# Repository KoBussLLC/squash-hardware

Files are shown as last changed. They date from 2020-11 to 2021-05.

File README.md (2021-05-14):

# Squash Keyboard Hardware

Small keyboard for big brains with lots of layers
🤏 ⌨️ 🧠 🍰

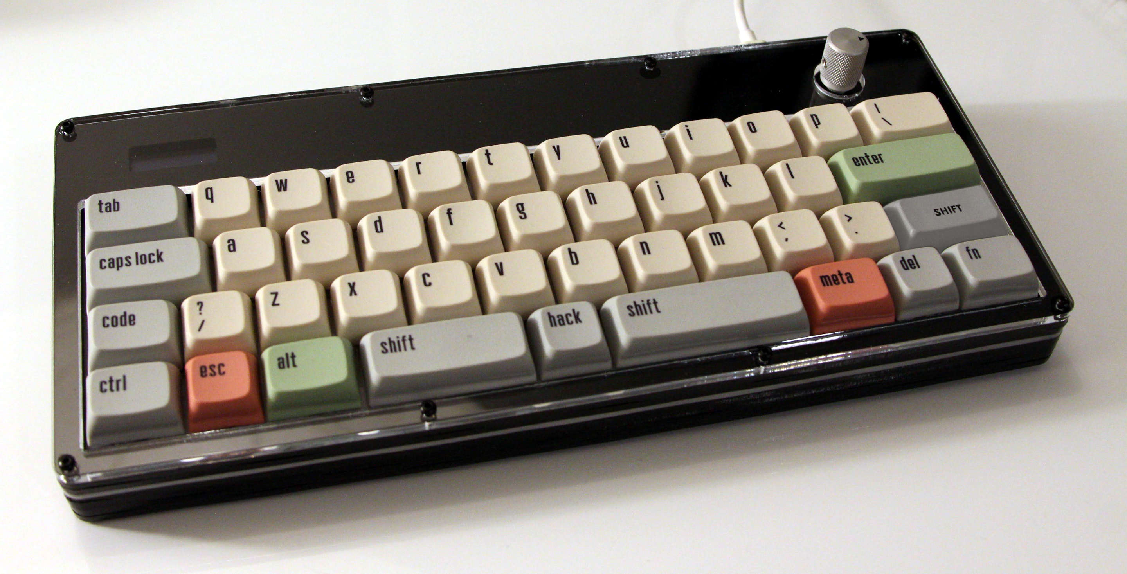
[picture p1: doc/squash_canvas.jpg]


This keyboard uses an acrylic case, POM switch-plate, and PCB mounted switches and stabilizers.

See Squash's bigger brother for [build instructions](https://github.com/KoBussLLC/grabert-hardware/blob/main/doc/BUILDGUIDE.md) and [additional information](https://github.com/KoBussLLC/grabert-hardware/blob/main/README.md).

## Layout

[Keyboard Layout Editor Permalink](http://www.keyboard-layout-editor.com/##@@_x:2.75&w:1.5%3B&=0,0&=0,1&=0,2&=0,3&=0,4&=0,5&=0,6&=0,7&=0,8&=0,9&=0,10&_w:1.5%3B&=0,11%3B&@_x:2.75&w:1.75%3B&=1,0&=1,1&=1,2&=1,3&=1,4&=1,5&=1,6&=1,7&=1,8&=1,9&_w:2.25%3B&=1,10%3B&@_x:0.25&w:1.25%3B&=2,0%0A%0A%0A0,1&=2,1%0A%0A%0A0,1&_x:0.25&w:2.25%3B&=2,0%0A%0A%0A0,0&=2,2&=2,3&=2,4&=2,5&=2,6&=2,7&=2,8&=2,9&=2,10&_w:1.75%3B&=2,11%3B&@_x:2.75&c=%23AAAAAA&w:1.25%3B&=3,0&=3,1&=3,2%0A%0A%0A1,0&_c=%23cccccc&w:6.25%3B&=3,4%0A%0A%0A1,0&_c=%23AAAAAA&w:1.25%3B&=3,6&=3,7&_w:1.25%3B&=3,8%3B&@_y:0.25&x:5&w:1.25%3B&=3,2%0A%0A%0A1,1&_c=%23cccccc&w:2.25%3B&=3,3%0A%0A%0A1,1&=3,4%0A%0A%0A1,1&_w:2.75%3B&=3,5%0A%0A%0A1,1&_x:4%3B&=3,11) for layout options.

A standard keycap set can be used as long as each "row" has the same profile and a 1.75u right shift key is included.

## PCB

This project uses KiCad for electrical CAD

### Electrical Design Constraings
- No diode matrix enabled by LQFP 100 Footprint
- STM32 Based Micro-controller
- USB-C
- PWM LED indicators for Caps Lock and modifiers
- PCB Mount switches
- Enocder and I2C OLED Display

## CAD

This project uses FreeCAD 0.19 for mechanical CAD. File names are prefixed with a unique, arbitrary alphanumeric code with the first character always being a alpha character.

### Required Addons
- Assembly 4
- fasteners
- kicadStepUpMod

### Mechanical Design Constraints
- 40% Keyboard Layout
- Split spacebar and left shift layout options
- Push Button Encoder
- OLED Screen
- Fully Laser Cut Case

### Acrylic Sheet Stackup

Main Case Stackup. 0 is the bottom of the case. Foot pieces are included in the D65_USBCutoutSpacer.svg file and are assembled with the smallest piece on the bottom.

| Sheet Number | FreeCAD File Name | Thickness | Material | Shape |
| - | - | - | - | - |
| 0 | O56_BottomPlate | 0.125 in | Acrylic |  |
| 1 | Y7X_ClosedSpacer | 0.125 in | Acrylic |  |
| 2 | D65_USBCutoutSpacer | 0.125 in | Acrylic |  *includes foot pieces |
| 3 | D65_USBCutoutSpacer | 0.125 in | Acrylic |  *includes foot pieces |
| 4 | S86_SwitchPlate | 0.0625 in | POM/Acetal |  |
| 5 | Y7X_ClosedSpacer | 0.125 in | Acrylic |  |
| 6 | Q45_OLEDCover | 0.125 in | Acrylic |  |
| 7 | O03_TopCover | 0.125 in | Acrylic |  |

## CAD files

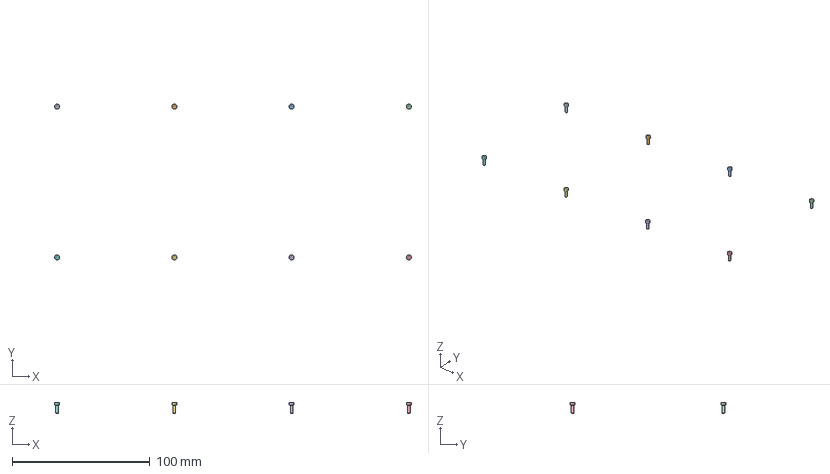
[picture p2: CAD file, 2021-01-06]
CAD/L32_Squash.FCStd
259.4 x 113.3 x 8.00 mm
M2x6-Screw001
M2x6-Screw
M2x6-Screw002
M2x6-Screw003
M2x6-Screw005
M2x6-Screw006
M2x6-Screw007
M2x6-Screw008

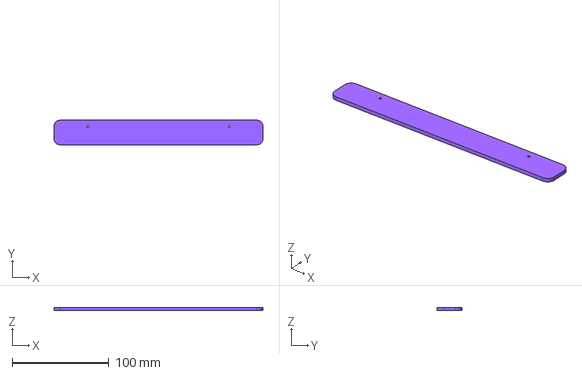
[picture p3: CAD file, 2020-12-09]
CAD/X23_Foot2.FCStd
215.9 x 25.4 x 3.17 mm

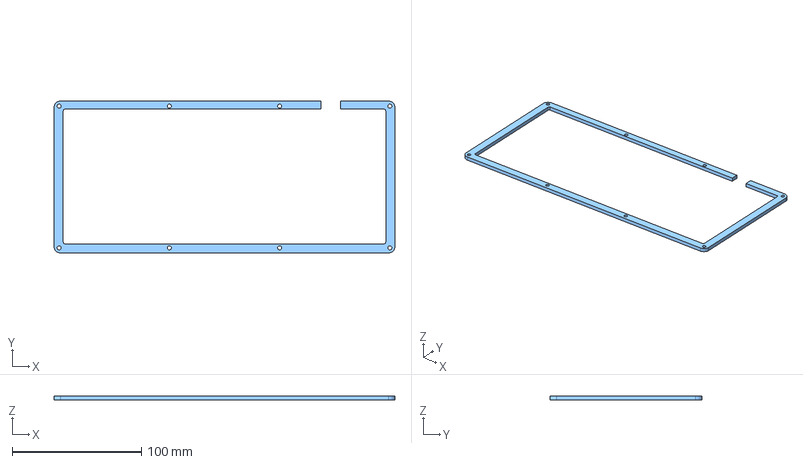
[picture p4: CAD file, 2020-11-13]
CAD/D65_USBCutoutSpacer.FCStd
263.5 x 117.5 x 3.17 mm

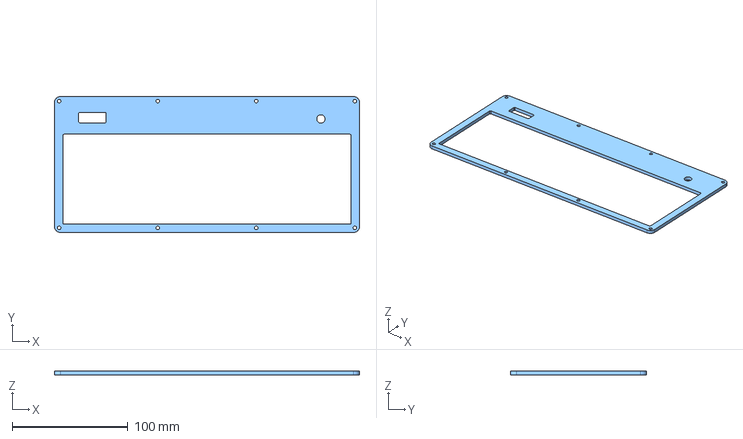
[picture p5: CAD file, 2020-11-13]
CAD/Q45_OLEDCover.FCStd
263.5 x 117.5 x 3.17 mm

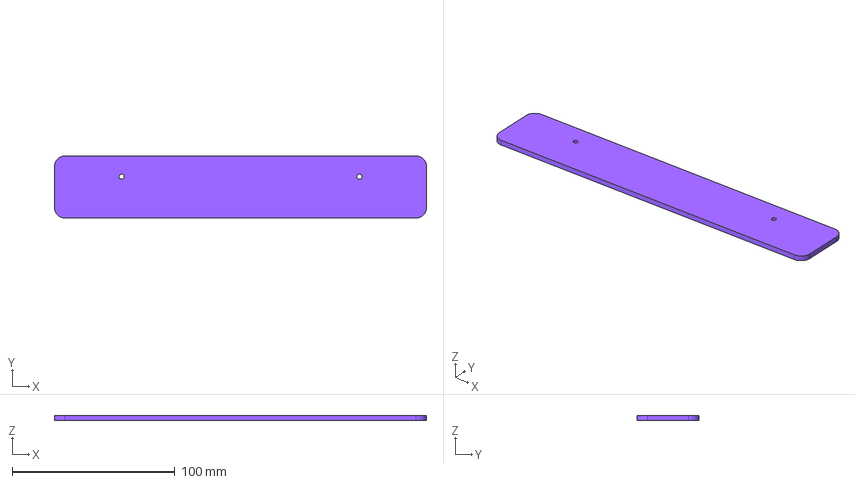
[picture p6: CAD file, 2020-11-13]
CAD/X21_Foot0.FCStd
228.6 x 38.1 x 3.17 mm

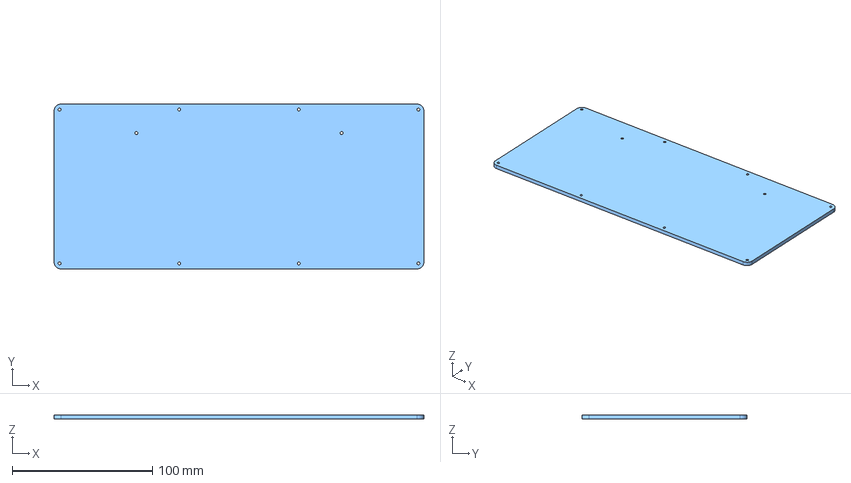
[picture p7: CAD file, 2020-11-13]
CAD/O56_BottomPlate.FCStd
263.5 x 117.5 x 3.17 mm

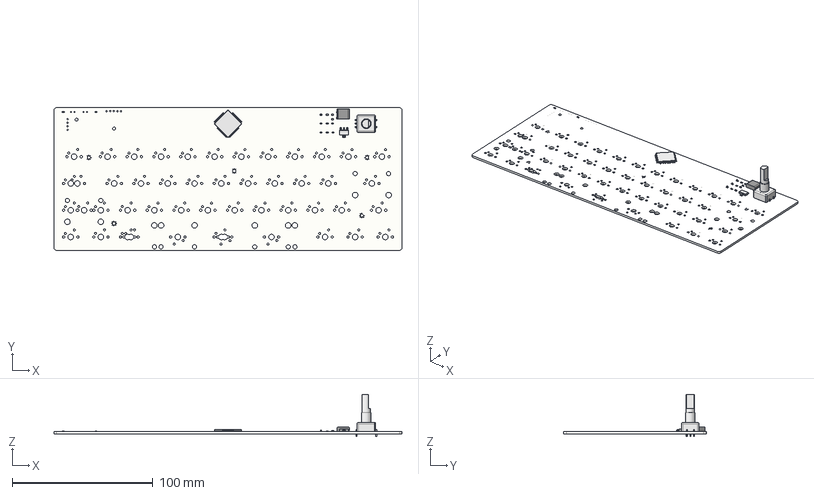
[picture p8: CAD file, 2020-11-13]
CAD/R79_SquashPCB.FCStd
247.7 x 101.6 x 30.2 mm
Pcb_de64
ROT_ENC1_PEC11R-4220K-S0024_5F30CEA1
U2_SOT_223_5F285D89
USBC1_U262-161N-4BVC11_5F1FC831
C1_C_0603_1608Metric_5F1FC55F x 2
D1_LED_0603_1608Metric_5F30C0E4 x 3
R1_R_0603_1608Metric_5F30E40D x 7
U1_LQFP_100_14x14mm_P05mm_5F30CB79

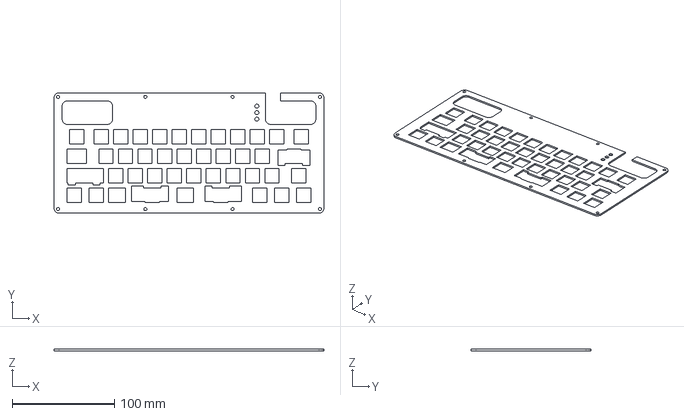
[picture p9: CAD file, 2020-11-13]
CAD/S86_SwitchPlate.FCStd
263.5 x 117.5 x 1.59 mm

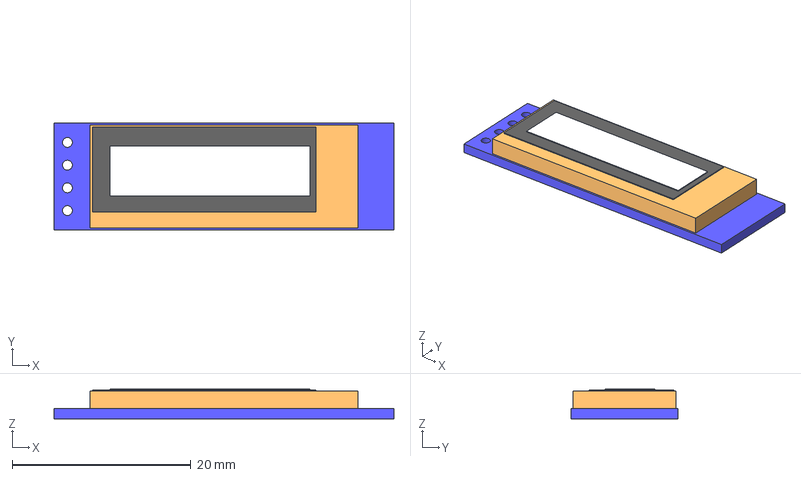
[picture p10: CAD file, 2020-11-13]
CAD/D19_Ssd1306Oled128x32.FCStd
38.0 x 12.0 x 3.35 mm
Glass
PCB
BlackFilm
Pixel Area

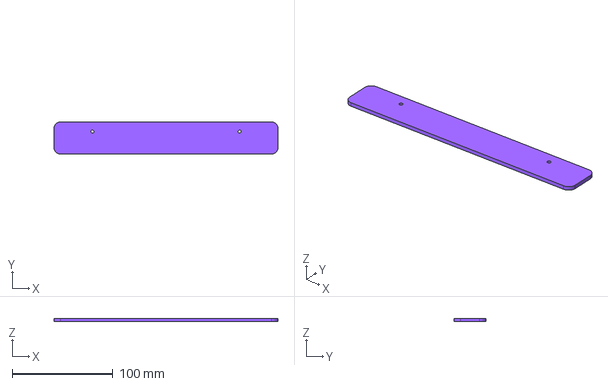
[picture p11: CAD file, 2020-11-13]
CAD/X22_Foot1.FCStd
222.2 x 31.8 x 3.17 mm

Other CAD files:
CAD/Y7X_ClosedSpacer.FCStd
CAD/O03_TopCover.FCStd

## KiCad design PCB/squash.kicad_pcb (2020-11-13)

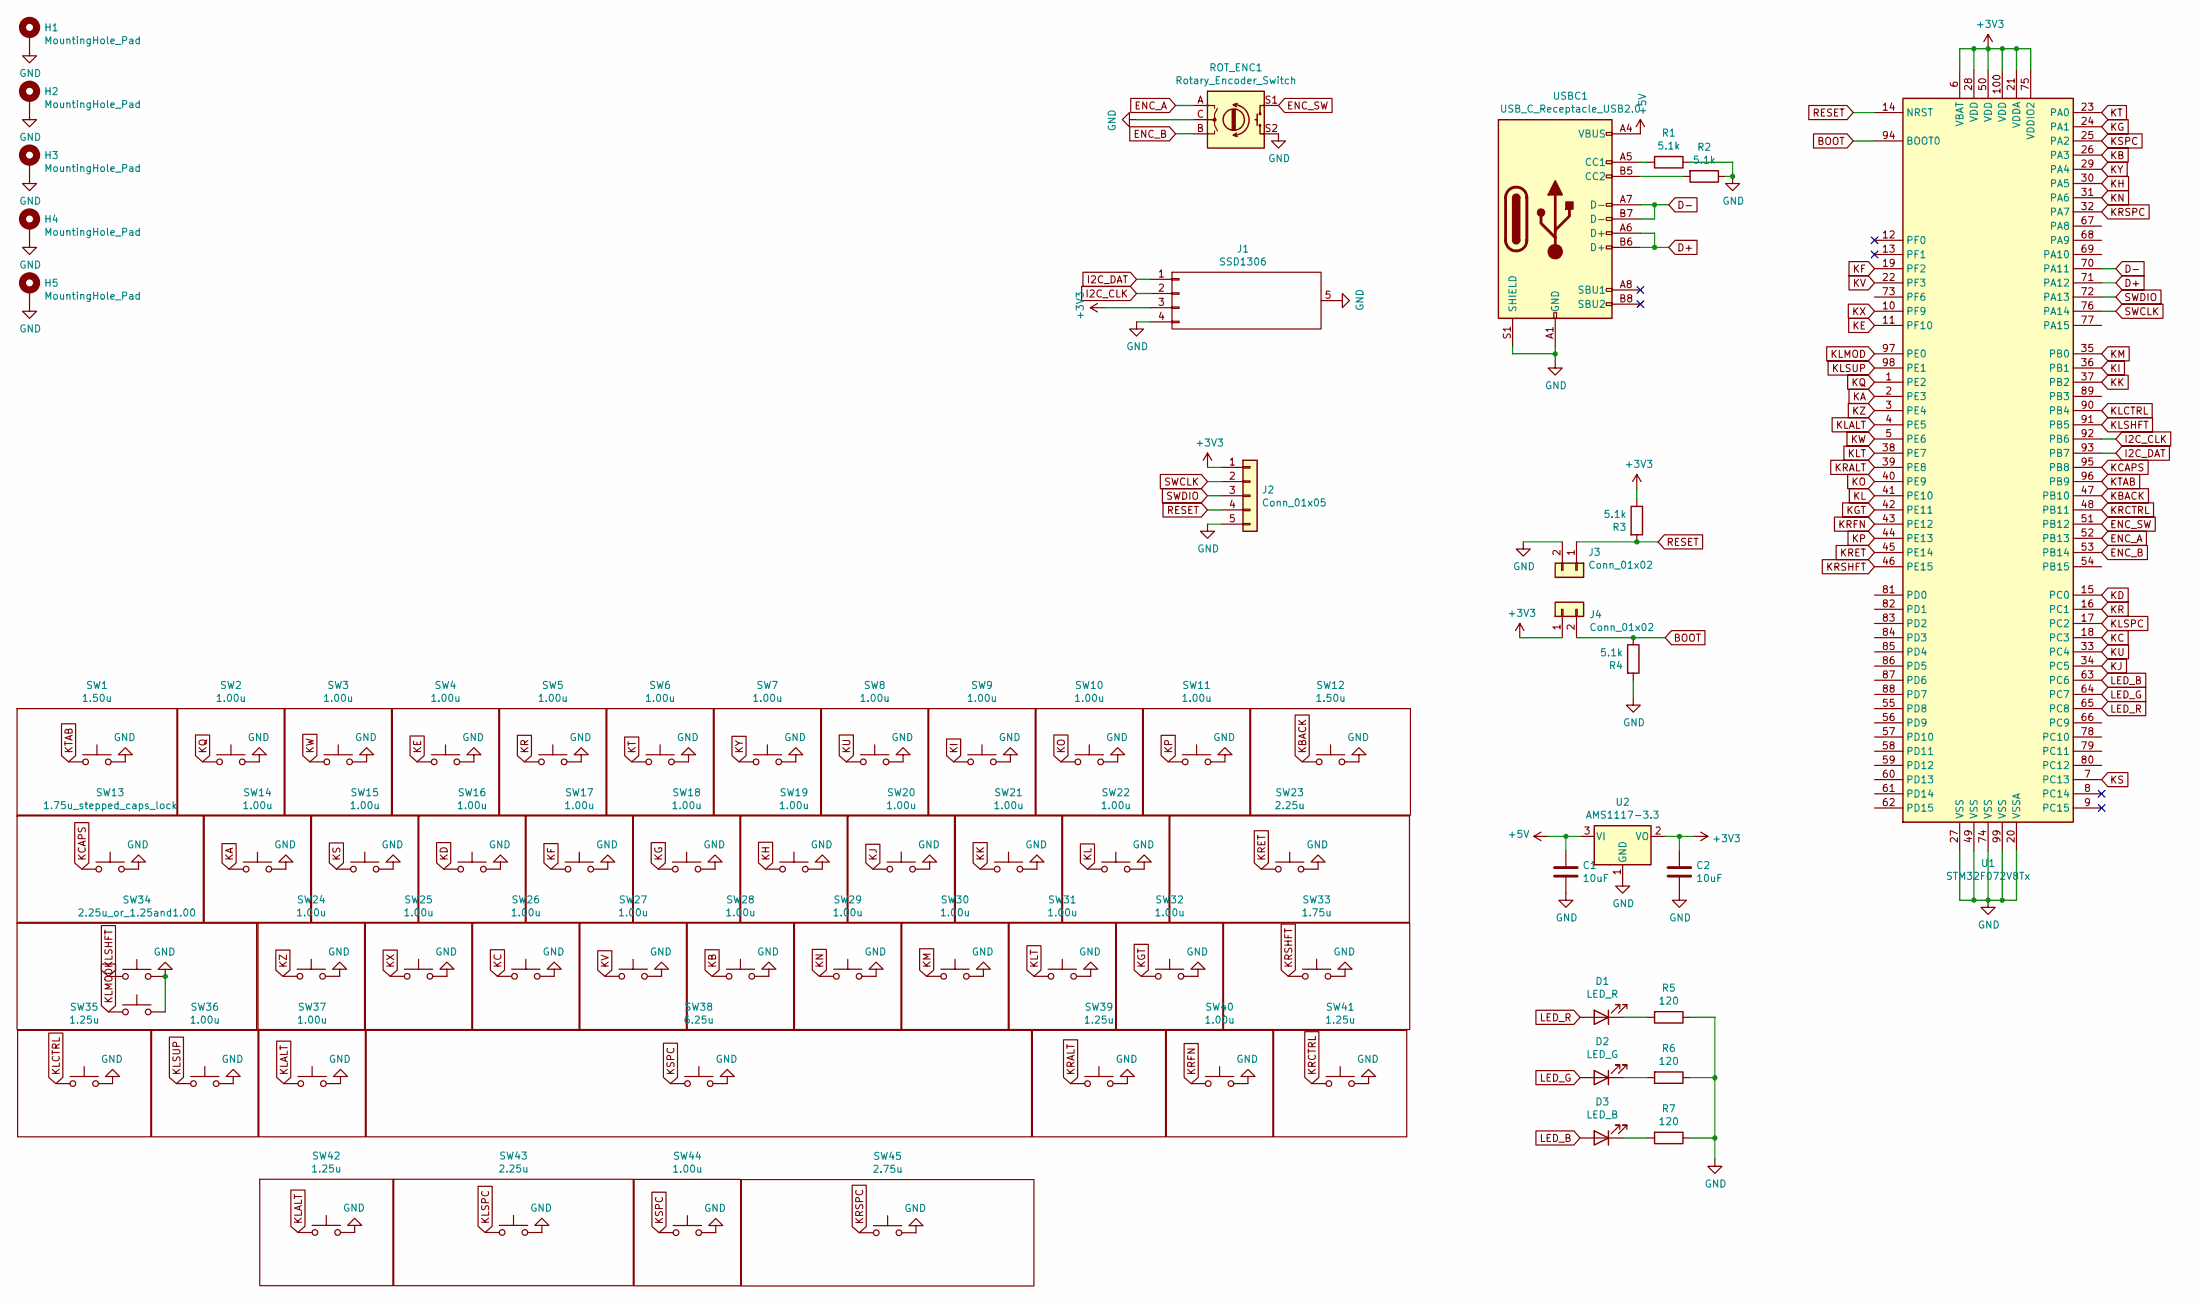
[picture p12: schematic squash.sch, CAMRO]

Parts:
C1, C2: 10uF; C_0603_1608Metric
D1: LED_R; LED_0603_1608Metric
D2: LED_G; LED_0603_1608Metric
D3: LED_B; LED_0603_1608Metric
H1, H2, H3, H4, H5: MountingHole_Pad; MountingHole_2.2mm_M2_Pad_Via
J1: SSD1306
J2: Conn_01x05; PinHeader_1x05_P2.54mm_Vertical
J3, J4: Conn_01x02; PinHeader_1x02_P2.54mm_Vertical
R1, R2, R3, R4: 5.1k; R_0603_1608Metric
R5, R6, R7: 120; R_0603_1608Metric
ROT_ENC1: Rotary_Encoder_Switch; RotaryEncoder_Alps_EC11E-Switch_Vertical_H20mm
SW1, SW12: 1.50u; MX_1.50u
SW2, SW3, SW4, SW5, SW6, SW7, SW8, SW9, SW10, SW11, SW14, SW15, SW16, SW17, SW18, SW19, SW20, SW21, SW22, SW24, SW25, SW26, SW27, SW28, SW29, SW30, SW31, SW32, SW36, SW37, SW40, SW44: 1.00u; MX_1u
SW13: 1.75u_stepped_caps_lock; MX_1.75u_stepped_caps
SW23, SW43: 2.25u; MX_2.25u
SW33: 1.75u; MX_1.75u
SW34: 2.25u_or_1.25and1.00; MX_2.25u_or_1.25and1.00
SW35, SW39, SW41, SW42: 1.25u; MX_1.25
SW38: 6.25u; MX_6.25u
SW45: 2.75u; MX_2.75u
U1: STM32F072V8Tx; LQFP-100_14x14mm_P0.5mm
U2: AMS1117-3.3; SOT-223-3_TabPin2
USBC1: USB_C_Receptacle_USB2.0; U262-161N-4BVC11

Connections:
+3V3: C2.1, J1.3 (VCC), J2.1, J4.1, R3.1, U1.6 (VBAT), U1.21 (VDDA), U1.28 (VDD), U1.50 (VDD), U1.75 (VDDIO2), U1.100 (VDD), U2.2 (VO)
+5V: C1.1, U2.3 (VI), USBC1.A4 (VBUS), USBC1.A9 (VBUS), USBC1.B4 (VBUS), USBC1.B9 (VBUS)
BOOT: J4.2, R4.1, U1.94 (BOOT0)
D+: U1.71 (PA12), USBC1.A6 (D+), USBC1.B6 (D+)
D-: U1.70 (PA11), USBC1.A7 (D-), USBC1.B7 (D-)
ENC_A: ROT_ENC1.A, U1.52 (PB13)
ENC_B: ROT_ENC1.B, U1.53 (PB14)
ENC_SW: ROT_ENC1.S1, U1.51 (PB12)
GND: C1.2, C2.2, H1.1, H2.1, H3.1, H4.1, H5.1, J1.4 (GND), J1.5 (MNT), J2.5, J3.2, R1.1, R2.1, R4.2, R5.1, R6.1, R7.1, ROT_ENC1.C, ROT_ENC1.S2, SW1.2, SW2.2, SW3.2, SW4.2, SW5.2, SW6.2, SW7.2, SW8.2, SW9.2, SW10.2, SW11.2, SW12.2, SW13.2, SW14.2, SW15.2, SW16.2, SW17.2, SW18.2, SW19.2, SW20.2, SW21.2, SW22.2, SW23.2, SW24.2, SW25.2, SW26.2, SW27.2, SW28.2, SW29.2, SW30.2, SW31.2, SW32.2, SW33.2, SW34.2, SW35.2, SW36.2, SW37.2, SW38.2, SW39.2, SW40.2, SW41.2, SW42.2, SW43.2, SW44.2, SW45.2, U1.20 (VSSA), U1.27 (VSS), U1.49 (VSS), U1.74 (VSS), U1.99 (VSS), U2.1 (GND), USBC1.A1 (GND), USBC1.A12 (GND), USBC1.B1 (GND), USBC1.B12 (GND), USBC1.S1 (SHIELD)
I2C_CLK: J1.2 (SCL), U1.92 (PB6)
I2C_DAT: J1.1 (SDA), U1.93 (PB7)
KA: SW14.1, U1.2 (PE3)
KB: SW28.1, U1.26 (PA3)
KBACK: SW12.1, U1.47 (PB10)
KC: SW26.1, U1.18 (PC3)
KCAPS: SW13.1, U1.95 (PB8)
KD: SW16.1, U1.15 (PC0)
KE: SW4.1, U1.11 (PF10)
KF: SW17.1, U1.19 (PF2)
KG: SW18.1, U1.24 (PA1)
KGT: SW32.1, U1.42 (PE11)
KH: SW19.1, U1.30 (PA5)
KI: SW9.1, U1.36 (PB1)
KJ: SW20.1, U1.34 (PC5)
KK: SW21.1, U1.37 (PB2)
KL: SW22.1, U1.41 (PE10)
KLALT: SW37.1, SW42.1, U1.4 (PE5)
KLCTRL: SW35.1, U1.90 (PB4)
KLMOD: SW34.3, U1.97 (PE0)
KLSHFT: SW34.1, U1.91 (PB5)
KLSPC: SW43.1, U1.17 (PC2)
KLSUP: SW36.1, U1.98 (PE1)
KLT: SW31.1, U1.38 (PE7)
KM: SW30.1, U1.35 (PB0)
KN: SW29.1, U1.31 (PA6)
KO: SW10.1, U1.40 (PE9)
KP: SW11.1, U1.44 (PE13)
KQ: SW2.1, U1.1 (PE2)
KR: SW5.1, U1.16 (PC1)
KRALT: SW39.1, U1.39 (PE8)
KRCTRL: SW41.1, U1.48 (PB11)
KRET: SW23.1, U1.45 (PE14)
KRFN: SW40.1, U1.43 (PE12)
KRSHFT: SW33.1, U1.46 (PE15)
KRSPC: SW45.1, U1.32 (PA7)
KS: SW15.1, U1.7 (PC13)
KSPC: SW38.1, SW44.1, U1.25 (PA2)
KT: SW6.1, U1.23 (PA0)
KTAB: SW1.1, U1.96 (PB9)
KU: SW8.1, U1.33 (PC4)
KV: SW27.1, U1.22 (PF3)
KW: SW3.1, U1.5 (PE6)
KX: SW25.1, U1.10 (PF9)
KY: SW7.1, U1.29 (PA4)
KZ: SW24.1, U1.3 (PE4)
LED_B: D3.2 (A), U1.63 (PC6)
LED_G: D2.2 (A), U1.64 (PC7)
LED_R: D1.2 (A), U1.65 (PC8)
unnamed: D1.1 (K), R5.2
unnamed: D2.1 (K), R6.2
unnamed: D3.1 (K), R7.2
unnamed: R1.2, USBC1.A5 (CC1)
unnamed: R2.2, USBC1.B5 (CC2)
RESET: J2.4, J3.1, R3.2, U1.14 (NRST)
SWCLK: J2.2, U1.76 (PA14)
SWDIO: J2.3, U1.72 (PA13)

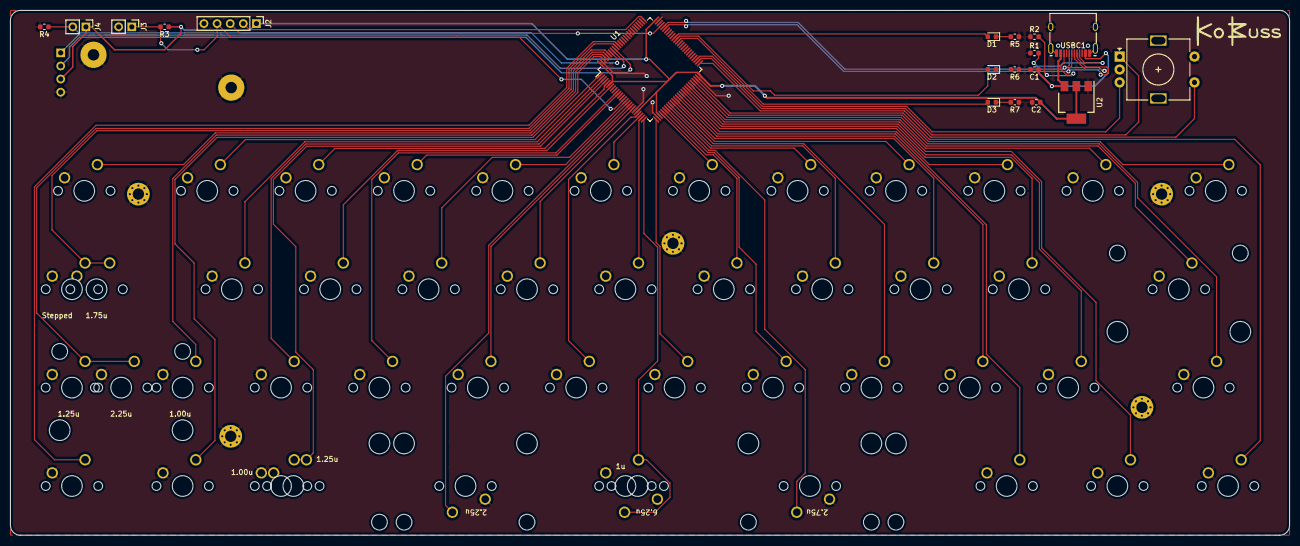
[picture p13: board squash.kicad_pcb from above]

Board: 2 copper layers, 247.7 x 101.6 mm, 73 parts (1 on the bottom side), 66 nets.

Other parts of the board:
Ref**: Val**; Squash2
Ref**#2, Ref**#3: Val**; kobuss_name

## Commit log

2020-10-24 V0 Squash PCB
    [squash.kicad_pcb, squash.sch]
2020-10-24 Initial switch plate CAD
    [1F2_SwitchPlate.FCStd]
2020-10-24 Case Clear Top Cover
    [O03_TopCover.FCStd]
2020-10-25 Case Foundation CAD
    [1F2_SwitchPlate.FCStd, D65_USBCutoutSpacer.FCStd, L32_Squash.FCStd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]
2020-11-13 Closed case with foot
    [D19_Ssd1306Oled128x32.FCStd, D65_USBCutoutSpacer.FCStd, L32_Squash.FCStd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]
2020-11-13 Left alt key pcb label, removal of logo
    [squash.kicad_pcb]
2020-12-09 Bottom foot hole dia down to 2.2mm
    [X23_Foot2.FCStd]
2021-01-06 Updated vector cut files
2021-01-06 assem update
    [L32_Squash.FCStd]
2021-05-14 V0 case finalize
